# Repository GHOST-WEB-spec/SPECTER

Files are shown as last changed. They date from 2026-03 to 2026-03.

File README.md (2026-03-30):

# ⚡ SPECTER

A handheld ESP32-based cybersecurity research tool running JINX OS. Built from scratch — custom firmware, custom PCB, custom 3D printed enclosure.

## ✨ Features

**📡 WiFi**
- Network scanner with OUI vendor lookup and threat assessment
- Probe request sniffer
- Evil Twin access point with captive portal credential capture
- KARMA attack — automatically impersonates known networks

**🔴 IR**
- TV-B-Gone (26 codes, all major brands)
- IR blaster with capture and replay
- IR self-test

**📶 BLE**
- Scanner with Apple device detection
- Apple BLE proximity spam (6 payloads)

**🔜 Coming Soon**
- CC1101 sub-GHz scanner and replay
- NFC read/write/clone
- RFID read/clone
- BadUSB payloads
- Deauth and beacon flood

## 🔧 Hardware

- ESP32-WROVER on Freenove extension board
- 2.8" ILI9341 TFT touchscreen (240x320)
- VS1838B IR receiver + TSAL6400 IR LEDs
- CC1101 x2 (sub-GHz radios)
- PN532 NFC module
- RDM6300 RFID module
- LiPo 1000mAh + TP4056 charging
- Custom KiCad PCB — ordered from JLCPCB
- 3D printed enclosure — Fusion 360

## 🚀 Status

Firmware working. PCB designed and ready to order. Parts arriving shortly for final assembly.

## 🛠️ Build

Flash using Arduino IDE with ESP32 core v2.0.17. Partition scheme: Huge APP 3MB No OTA.

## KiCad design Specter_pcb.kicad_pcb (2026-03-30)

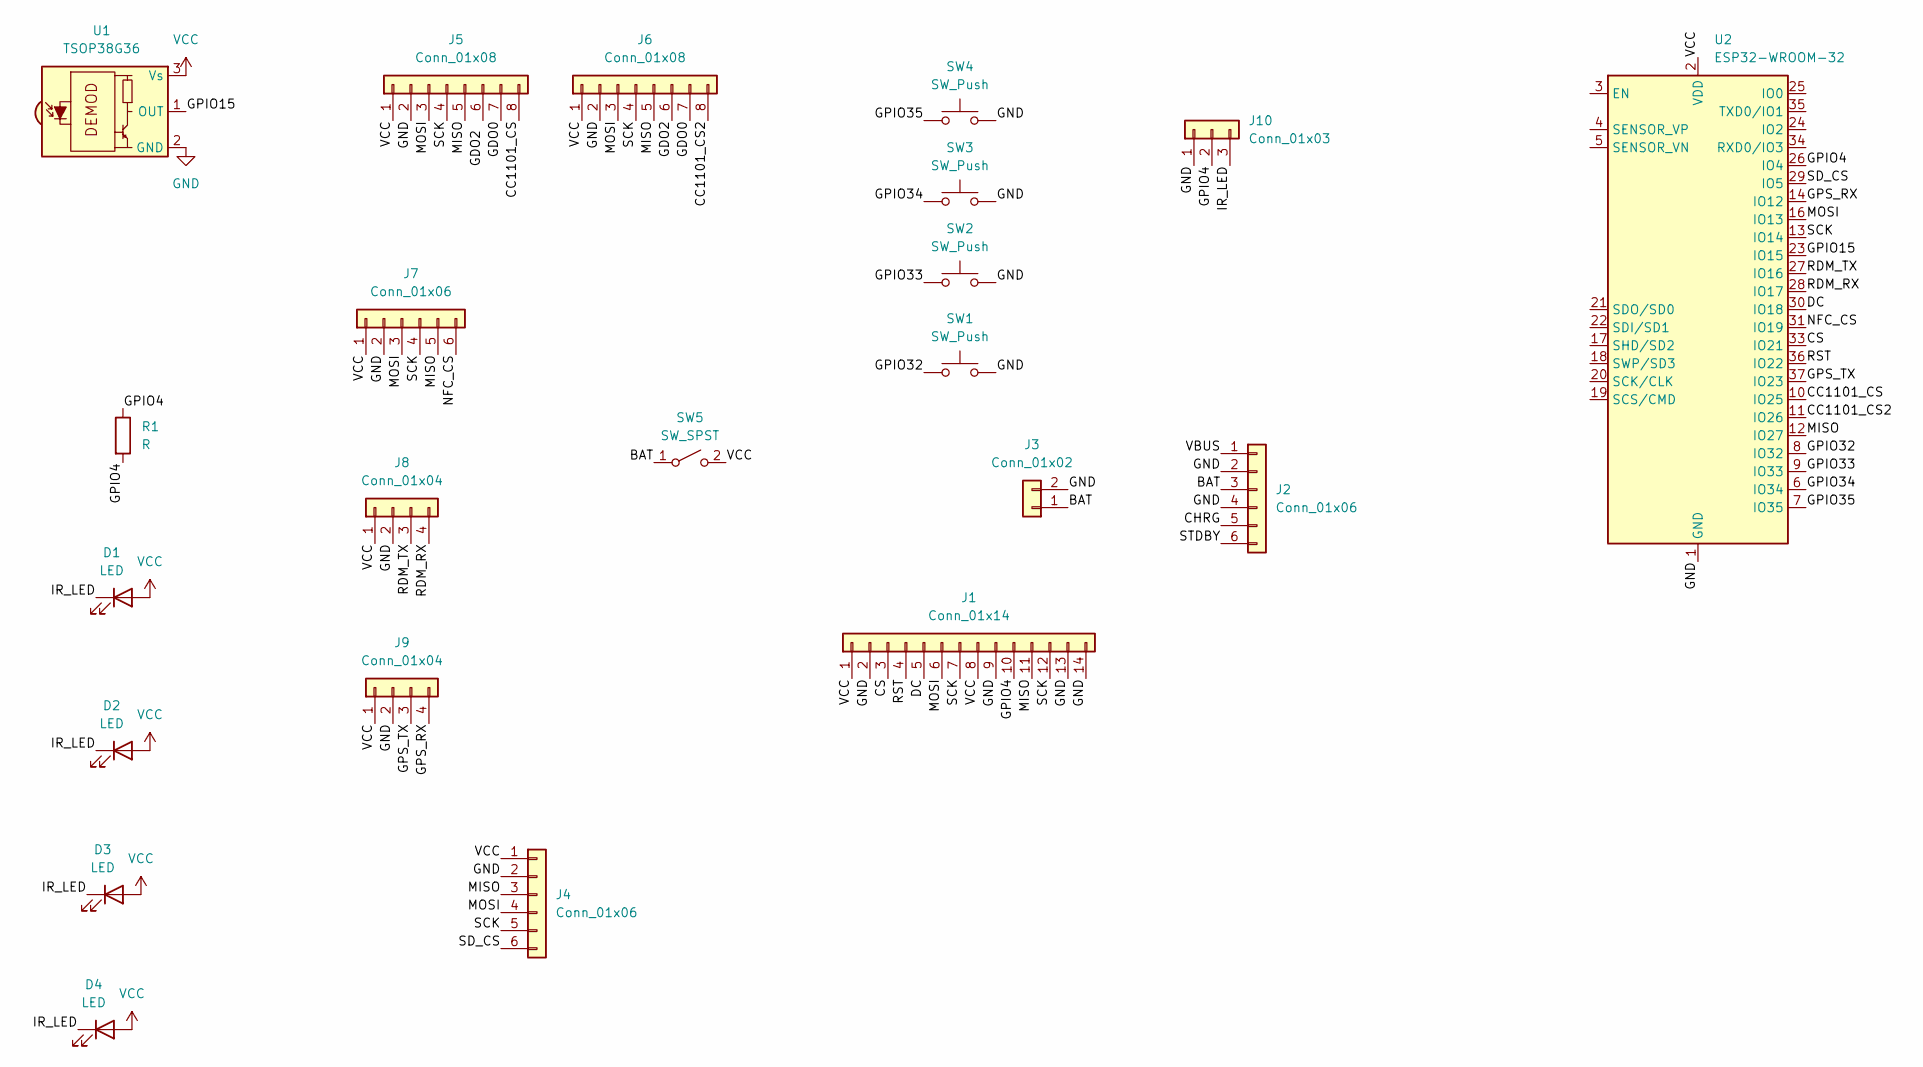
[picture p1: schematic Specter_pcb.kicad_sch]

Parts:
D1, D2, D3, D4: LED; LED_D5.0mm
J1: Conn_01x14; PinHeader_1x14_P2.54mm_Vertical
J2, J4, J7: Conn_01x06; PinHeader_1x06_P2.54mm_Vertical
J3: Conn_01x02; JST_PH_S2B-PH-K_1x02_P2.00mm_Horizontal
J5, J6: Conn_01x08; PinHeader_1x08_P2.54mm_Vertical
J8, J9: Conn_01x04; PinHeader_1x04_P2.54mm_Vertical
J10: Conn_01x03; PinHeader_1x03_P2.54mm_Vertical
R1: R; R_Axial_DIN0207_L6.3mm_D2.5mm_P7.62mm_Horizontal
SW1, SW2, SW3, SW4: SW_Push; SW_PUSH_6mm
SW5: SW_SPST; SW_NKK_BB15AH
U1: TSOP38G36; Vishay_MINICAST-3Pin
U2: ESP32-WROOM-32

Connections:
/BAT: J2.3, J3.1, SW5.1 (A)
/CC1101_CS: J5.8, U2.10 (IO25)
/CC1101_CS2: J6.8, U2.11 (IO26)
/CHRG: J2.5
/CS: J1.3, U2.33 (IO21)
/DC: J1.5, U2.30 (IO18)
/GDO0: J5.7, J6.7
/GDO2: J6.6
/GPIO4: J1.10, J10.2, R1.1, R1.2, U2.26 (IO4)
/GPIO15: U1.1 (OUT), U2.23 (IO15)
/GPIO32: SW1.1, U2.8 (IO32)
/GPIO33: SW2.1, U2.9 (IO33)
/GPIO34: SW3.1, U2.6 (IO34)
/GPIO35: SW4.1, U2.7 (IO35)
/GPS_RX: J9.4, U2.14 (IO12)
/GPS_TX: J9.3, U2.37 (IO23)
/IR_LED: D1.1 (K), D2.1 (K), D3.1 (K), D4.1 (K), J10.3
/MISO: J1.11, J4.3, J5.5, J6.5, J7.5, U2.12 (IO27)
/MOSI: J1.6, J4.4, J5.3, J6.3, J7.3, U2.16 (IO13)
/NFC_CS: J7.6, U2.31 (IO19)
/RDM_RX: J8.4, U2.28 (IO17)
/RDM_TX: J8.3, U2.27 (IO16)
/RST: J1.4, U2.36 (IO22)
/SCK: J1.7, J1.12, J4.5, J5.4, J6.4, J7.4, U2.13 (IO14)
/SD_CS: J4.6, U2.29 (IO5)
/STDBY: J2.6
/VBUS: J2.1
GND: J1.2, J1.9, J1.13, J1.14, J2.2, J2.4, J3.2, J4.2, J5.2, J6.2, J7.2, J8.2, J9.2, J10.1, SW1.2, SW2.2, SW3.2, SW4.2, U1.2 (GND), U2.1 (GND), U2.15 (GND), U2.38 (GND), U2.39 (GND)
VCC: D1.2 (A), D2.2 (A), D3.2 (A), D4.2 (A), J1.1, J1.8, J4.1, J5.1, J6.1, J7.1, J8.1, J9.1, SW5.2 (B), U1.3 (Vs), U2.2 (VDD)

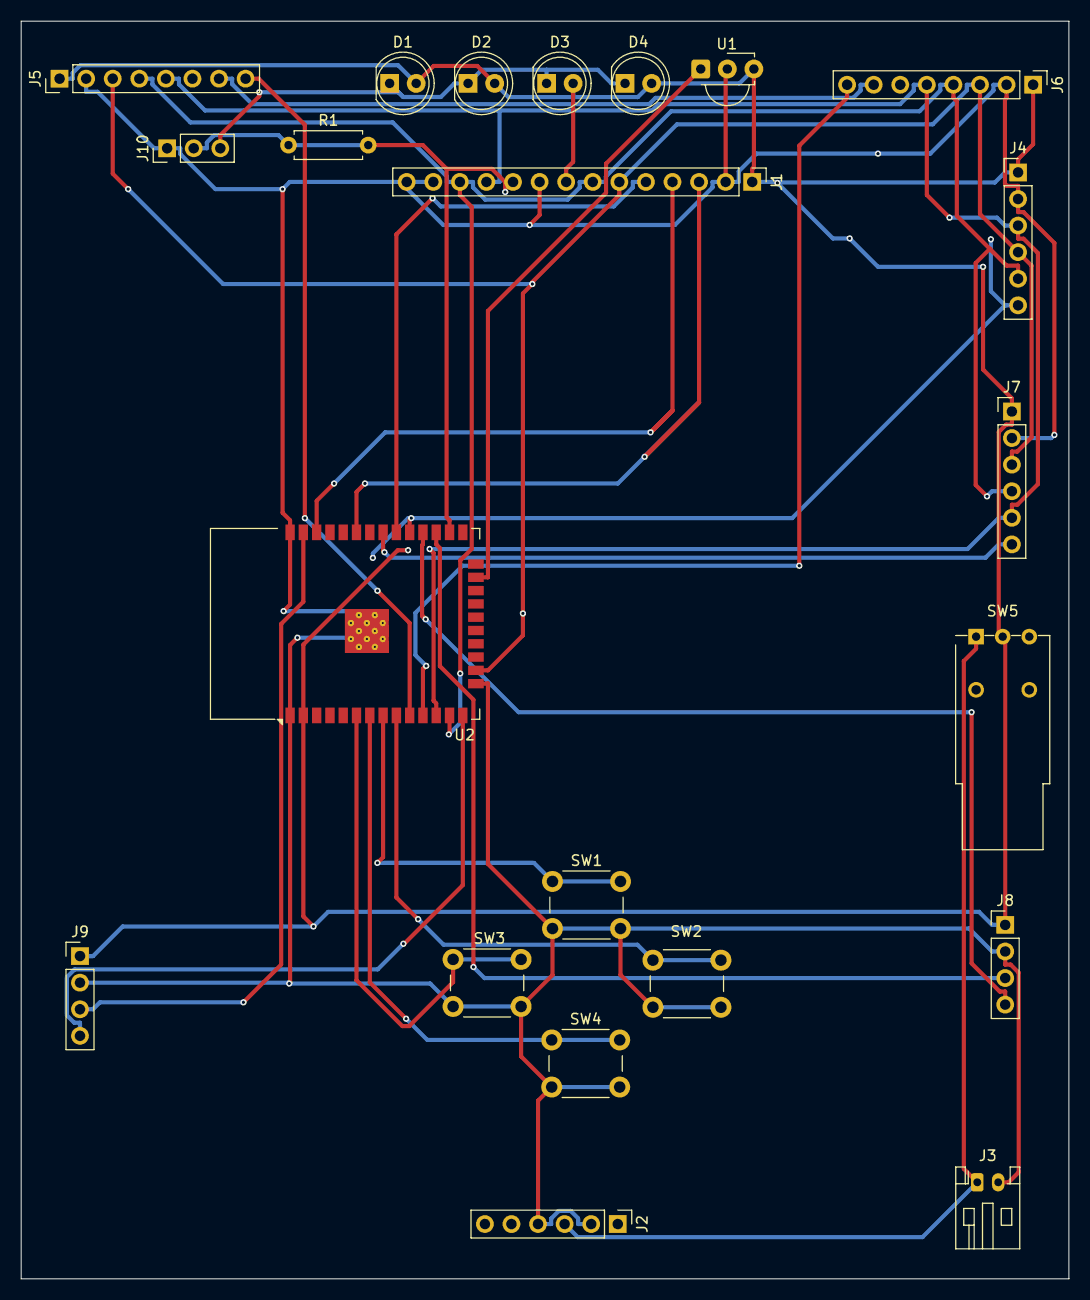
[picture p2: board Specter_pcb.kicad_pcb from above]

Board: 2 copper layers, 100.1 x 120.2 mm, 22 parts (0 on the bottom side), 25 nets.

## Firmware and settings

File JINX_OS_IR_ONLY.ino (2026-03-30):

// ============================================================
// JINX OS v9 — SPECTER
// Terminal Style UI — Green on Black
// ============================================================

#include <TFT_eSPI.h>
#include <SPI.h>
#include <IRremote.hpp>
#include <WiFi.h>
#include "esp_wifi.h"
#include <BLEDevice.h>
#include <BLEScan.h>
#include <BLEAdvertisedDevice.h>
#include <BLEAdvertising.h>
#include <WebServer.h>
#include <DNSServer.h>

// --- Pin definitions ---
#define IR_RECV_PIN  15
#define IR_BLAST_PIN 4

TFT_eSPI tft = TFT_eSPI();

// ============================================================
// COLOUR PALETTE
// ============================================================
#define C_BG       0x0000
#define C_GREEN    0x07E0
#define C_DGREEN   0x03E0
#define C_DDGREEN  0x01C0
#define C_WHITE    0xFFFF
#define C_GREY     0x8410
#define C_DGREY    0x2104
#define C_RED      0xF800
#define C_YELLOW   0xFFE0
#define C_CYAN     0x07FF
#define C_ORANGE   0xFD20
#define C_PURPLE   0x780F
#define C_BLUE     0x001F

// ============================================================
// STATES
// ============================================================
enum State {
  S_SPLASH, S_HOME,
  S_IR_MENU, S_IR_BLASTER, S_IR_TVBGONE, S_IR_SELFTEST,
  S_WIFI_MENU, S_WIFI_SCANNER, S_WIFI_DETAIL, S_WIFI_ATTACKS,
  S_WIFI_BEACON, S_WIFI_PROBE,
  S_BLE_MENU, S_BLE_SCANNER, S_BLE_SPAM,
  S_EVIL_TWIN, S_KARMA
};
State currentState = S_SPLASH;

// --- WiFi ---
int wifiCount     = 0;
int wifiScroll    = 0;
int wifiDetailIdx = -1;
bool wifiSortSig  = true;
int wifiIdx[64];

// --- Probe sniffer ---
bool probeRunning = false;
struct ProbeEntry { char mac[18]; char ssid[33]; int rssi; };
#define MAX_PROBES 20
ProbeEntry probeLog[MAX_PROBES];
int probeCount  = 0;
int probeScroll = 0;

// --- Evil Twin ---
bool evilTwinRunning = false;
int  evilTwinTargetIdx = -1;
struct CredEntry { char email[64]; char pass[64]; };
#define MAX_CREDS 20
CredEntry credLog[MAX_CREDS];
int credCount  = 0;
int credScroll = 0;
WebServer* evilServer = nullptr;
DNSServer* evilDNS    = nullptr;

// --- KARMA ---
#define KARMA_TARGET_SSID "TBFT"
bool karmaRunning = false;
struct KarmaEntry { char ssid[33]; char mac[18]; int count; };
#define MAX_KARMA 20
KarmaEntry karmaLog[MAX_KARMA];
int karmaCount  = 0;
int karmaScroll = 0;
WebServer* karmaServer = nullptr;
DNSServer* karmaDNS    = nullptr;

// --- BLE scanner ---
struct BLEEntry {
  char name[32];
  char mac[18];
  int  rssi;
  bool isApple;
};
#define MAX_BLE 30
BLEEntry bleLog[MAX_BLE];
int bleCount   = 0;
int bleScroll  = 0;
bool bleScanning = false;
BLEScan* pBLEScan = nullptr;

// --- BLE spam ---
bool bleSpamRunning = false;
int  bleSpamIdx     = 0;
int  bleSpamSent    = 0;

// --- IR ---
bool irListening = false;
bool irHasCode   = false;
uint32_t irValue = 0;
uint16_t irBits  = 0;
uint8_t  irProto = 0;

// --- Touch ---
uint16_t tx, ty;
unsigned long lastTouch = 0;
#define DEBOUNCE_MS 280

struct TVCode { uint8_t proto; uint32_t value; uint8_t bits; const char* brand; };

// ============================================================
// TOUCH
// ============================================================
bool getTouch(uint16_t &x, uint16_t &y) {
  uint16_t rx, ry;
  if (!tft.getTouch(&rx, &ry)) return false;
  x = map(ry, 299, 12, 0, 239);
  y = map(rx, 226, 11, 0, 319);
  x = constrain(x, 0, 239);
  y = constrain(y, 0, 319);
  return true;
}

// ============================================================
// PRIMITIVES
// ============================================================
void drawBar(const char* left, const char* right) {
  tft.fillRect(0, 0, 240, 14, C_DGREEN);
  tft.setTextColor(C_BG, C_DGREEN); tft.setTextSize(1);
  tft.setCursor(3, 3); tft.print(left);
  int rlen = strlen(right) * 6;
  tft.setCursor(237 - rlen, 3); tft.print(right);
}
void drawHeader(int y, const char* text) {
  tft.setTextColor(C_GREEN, C_BG); tft.setTextSize(1);
  tft.setCursor(0, y); tft.print("-- "); tft.print(text); tft.print(" ");
  int used = 3 + strlen(text) + 1;
  for (int i = used * 6; i < 240; i += 6) tft.print("-");
}
void drawBack() {
  tft.setTextColor(C_DGREEN, C_BG); tft.setTextSize(1);
  tft.setCursor(0, 17); tft.print("[<] BACK");
}
void drawBtn(int y, int h, const char* label, uint16_t col, bool active = true) {
  uint16_t bg = active ? C_DGREY : C_BG;
  tft.fillRect(0, y, 240, h, bg);
  tft.drawRect(0, y, 240, h, active ? col : C_DGREY);
  tft.fillRect(0, y, 3, h, col);
  tft.setTextColor(active ? col : C_DGREY, bg); tft.setTextSize(2);
  int tx2 = (240 - strlen(label) * 12) / 2;
  tft.setCursor(tx2, y + h/2 - 8); tft.print(label);
}
void drawTag(int x, int y, const char* text, uint16_t col) {
  int w = strlen(text) * 6 + 4;
  tft.drawRect(x, y, w, 10, col);
  tft.setTextColor(col, C_BG); tft.setTextSize(1);
  tft.setCursor(x + 2, y + 2); tft.print(text);
}
void drawHR(int y, uint16_t col = C_DGREEN) { tft.drawFastHLine(0, y, 240, col); }
bool backTapped(uint16_t x, uint16_t y) { return (y >= 0 && y <= 14); }

// ============================================================
// SPLASH
// ============================================================
void drawOniMask(int cx, int cy, int r) {
  tft.fillCircle(cx, cy, r, C_BG);
  tft.drawCircle(cx, cy, r, C_GREEN); tft.drawCircle(cx, cy, r-1, C_DGREEN);
  tft.fillCircle(cx-r/3, cy-r/6, r/5, C_GREEN); tft.fillCircle(cx+r/3, cy-r/6, r/5, C_GREEN);
  tft.fillCircle(cx-r/3, cy-r/6, r/10, C_BG);   tft.fillCircle(cx+r/3, cy-r/6, r/10, C_BG);
  tft.fillCircle(cx-r/3, cy-r/6, r/16, C_GREEN); tft.fillCircle(cx+r/3, cy-r/6, r/16, C_GREEN);
  tft.drawLine(cx-r/2, cy-r/2, cx-r/6, cy-r/3, C_GREEN);
  tft.drawLine(cx+r/2, cy-r/2, cx+r/6, cy-r/3, C_GREEN);
  tft.fillTriangle(cx, cy, cx-r/8, cy+r/4, cx+r/8, cy+r/4, C_DGREEN);
  tft.drawLine(cx-r/3, cy+r/2, cx+r/3, cy+r/2, C_GREEN);
  tft.drawLine(cx-r/3, cy+r/2, cx-r/2, cy+r/3, C_GREEN);
  tft.drawLine(cx+r/3, cy+r/2, cx+r/2, cy+r/3, C_GREEN);
  tft.fillRect(cx-r/4, cy+r/2-2, r/6, r/8, C_GREEN);
  tft.fillRect(cx+r/8, cy+r/2-2, r/6, r/8, C_GREEN);
  tft.fillTriangle(cx-r/2, cy-r, cx-r/3, cy-r-r/3, cx-r/6, cy-r, C_GREEN);
  tft.fillTriangle(cx+r/2, cy-r, cx+r/3, cy-r-r/3, cx+r/6, cy-r, C_GREEN);
}
void showSplash() {
  tft.fillScreen(C_BG);
  drawOniMask(120, 110, 55);
  tft.setTextColor(C_GREEN, C_BG); tft.setTextSize(3);
  tft.setCursor(28, 180); tft.print("SPECTER");
  tft.setTextColor(C_DGREEN, C_BG); tft.setTextSize(1);
  tft.setCursor(66, 207); tft.print("JINX OS v2.0");
  drawHR(220, C_DDGREEN); drawHR(222, C_DDGREEN);
  const char* bootLines[] = {
    "init hardware...", "mounting flash...",
    "loading IR db...", "wifi ready...", "boot ok."
  };
  int by = 228;
  for (int i = 0; i < 5; i++) {
    tft.setTextColor(C_DDGREEN, C_BG); tft.setTextSize(1);
    tft.setCursor(0, by); tft.print("> ");
    tft.setTextColor(C_DGREEN, C_BG); tft.print(bootLines[i]);
    by += 10; delay(120);
  }
  delay(400);
}

// ============================================================
// HOME
// ============================================================
void drawHomeScreen() {
  tft.fillScreen(C_BG);
  drawBar("SPECTER//JINX OS v2.0", "HOME");
  drawHR(14, C_DDGREEN);
  drawHeader(18, "SELECT MODULE");

  // IR
  tft.fillRect(0, 34, 240, 40, C_BG);
  tft.drawRect(0, 34, 240, 40, C_DGREEN);
  tft.fillRect(0, 34, 3, 40, C_RED);
  tft.setTextColor(C_RED, C_BG); tft.setTextSize(1); tft.setCursor(10, 38); tft.print("[IR]");
  tft.setTextColor(C_GREEN, C_BG); tft.setTextSize(2); tft.setCursor(10, 50); tft.print("INFRARED");
  drawHR(75, C_DDGREEN);

  // WiFi
  tft.fillRect(0, 77, 240, 40, C_BG);
  tft.drawRect(0, 77, 240, 40, C_DGREEN);
  tft.fillRect(0, 77, 3, 40, C_CYAN);
  tft.setTextColor(C_CYAN, C_BG); tft.setTextSize(1); tft.setCursor(10, 81); tft.print("[WiFi]");
  tft.setTextColor(C_GREEN, C_BG); tft.setTextSize(2); tft.setCursor(10, 93); tft.print("WIRELESS");
  drawHR(118, C_DDGREEN);

  // BLE
  tft.fillRect(0, 120, 240, 40, C_BG);
  tft.drawRect(0, 120, 240, 40, C_DGREEN);
  tft.fillRect(0, 120, 3, 40, C_BLUE);
  tft.setTextColor(C_BLUE, C_BG); tft.setTextSize(1); tft.setCursor(10, 124); tft.print("[BLE]");
  tft.setTextColor(C_GREEN, C_BG); tft.setTextSize(2); tft.setCursor(10, 136); tft.print("BLUETOOTH");
  drawHR(161, C_DDGREEN);

  tft.setTextColor(C_DDGREEN, C_BG); tft.setTextSize(1);
  tft.setCursor(0, 168); tft.print("> [SUB-GHZ]  coming soon");
  tft.setCursor(0, 181); tft.print("> [NFC]      coming soon");
  tft.setCursor(0, 194); tft.print("> [BADUSB]   coming soon");
  drawHR(207, C_DDGREEN);
  tft.setTextColor(C_DDGREEN, C_BG);
  tft.setCursor(0, 211); tft.print("specter//ready_");
}

bool homeIRTapped(uint16_t x, uint16_t y)   { return (y >= 34  && y <= 75); }
bool homeWiFiTapped(uint16_t x, uint16_t y) { return (y >= 77  && y <= 118); }
bool homeBLETapped(uint16_t x, uint16_t y)  { return (y >= 120 && y <= 161); }

// ============================================================
// IR MENU
// ============================================================
void drawIRMenu() {
  tft.fillScreen(C_BG);
  drawBar("SPECTER//IR", "INFRARED");
  drawBack();
  drawHeader(30, "IR MODULE");
  drawBtn(42, 55, "IR BLASTER", C_RED, true);
  tft.setTextColor(C_DGREEN, C_DGREY); tft.setTextSize(1);
  tft.setCursor(6, 75); tft.print("capture + replay IR codes");
  drawHR(98, C_DDGREEN);
  drawBtn(101, 55, "TV-B-GONE", C_DGREEN, true);
  tft.setTextColor(C_DGREEN, C_DGREY); tft.setTextSize(1);
  tft.setCursor(6, 134); tft.print("blast all TV power codes");
  drawTag(178, 103, "READY", C_DGREEN);
  drawHR(157, C_DDGREEN);
  drawBtn(160, 55, "SELF TEST", C_YELLOW, true);
  tft.setTextColor(C_DGREEN, C_DGREY); tft.setTextSize(1);
  tft.setCursor(6, 193); tft.print("loop test: blast+recv verify");
  drawTag(165, 162, "DIAG", C_YELLOW);
}
bool irMenuBlasterTapped(uint16_t x, uint16_t y)  { return (y >= 42  && y <= 97); }
bool irMenuTVBGoneTapped(uint16_t x, uint16_t y)  { return (y >= 101 && y <= 156); }
bool irMenuSelfTestTapped(uint16_t x, uint16_t y) { return (y >= 160 && y <= 215); }

// ============================================================
// IR BLASTER
// ============================================================
void drawIRBlaster() {
  tft.fillScreen(C_BG);
  drawBar("SPECTER//IR", "BLASTER");
  drawBack();
  drawHeader(30, "IR BLASTER");
  tft.drawRect(0, 42, 240, 72, C_DGREEN);
  tft.fillRect(0, 42, 3, 72, irHasCode ? C_GREEN : C_DGREY);
  if (!irHasCode) {
    tft.setTextColor(C_DGREEN, C_BG); tft.setTextSize(1);
    tft.setCursor(6, 50); tft.print("> no signal captured");
    tft.setCursor(6, 63); tft.print("> press LISTEN");
    tft.setCursor(6, 76); tft.print("> point remote at GPIO15");
    tft.setTextColor(C_DDGREEN, C_BG); tft.setCursor(6, 95); tft.print("status: waiting_");
  } else {
    tft.setTextColor(C_GREEN, C_BG); tft.setTextSize(1);
    tft.setCursor(6, 50); tft.print("> signal locked");
    tft.setTextColor(C_DGREEN, C_BG); tft.setCursor(6, 63); tft.print("proto: ");
    tft.setTextColor(C_GREEN, C_BG); tft.print(getProtocolString((decode_type_t)irProto));
    tft.setTextColor(C_DGREEN, C_BG); tft.setCursor(6, 76); tft.print("value: ");
    tft.setTextColor(C_YELLOW, C_BG); tft.print("0x"); tft.print(irValue, HEX);
    tft.setTextColor(C_DGREEN, C_BG); tft.setCursor(6, 89); tft.print("bits:  ");
    tft.setTextColor(C_GREEN, C_BG); tft.print(irBits);
    tft.setCursor(170, 95); tft.print("[LOCKED]");
  }
  drawHR(115, C_DDGREEN);
  uint16_t lCol = irListening ? C_GREEN : C_DGREEN;
  drawBtn(118, 50, irListening ? "// LISTENING" : "LISTEN", lCol, true);
  if (irListening) {
    tft.setTextColor(C_GREEN, C_DGREY); tft.setTextSize(1);
    tft.setCursor(6, 154); tft.print("receiving on GPIO15...");
  }
  drawHR(169, C_DDGREEN);
  drawBtn(172, 50, "BLAST", irHasCode ? C_RED : C_DGREY, irHasCode);
  if (!irHasCode) {
    tft.setTextColor(C_DGREY, C_BG); tft.setTextSize(1);
    tft.setCursor(6, 208); tft.print("capture a signal first");
  }
}
bool irBlasterListenTapped(uint16_t x, uint16_t y) { return (y >= 118 && y <= 168); }
bool irBlasterBlastTapped(uint16_t x, uint16_t y)  { return (y >= 172 && y <= 222); }

void doBlast() {
  if (!irHasCode) return;
  tft.fillScreen(C_BG); drawBar("SPECTER//IR", "TRANSMIT");
  tft.setTextColor(C_RED, C_BG); tft.setTextSize(2);
  tft.setCursor(40, 120); tft.print("BLASTING...");
  tft.setTextColor(C_DGREEN, C_BG); tft.setTextSize(1);
  tft.setCursor(0, 150); tft.print("> transmitting IR signal");
  tft.setCursor(0, 163); tft.print("> repeat x15");
  delay(200);
  IRData irData;
  irData.protocol = (decode_type_t)irProto;
  irData.address  = (irValue >> 16) & 0xFFFF;
  irData.command  = irValue & 0xFFFF;
  irData.numberOfBits = irBits; irData.flags = 0;
  IrSender.begin(IR_BLAST_PIN);
  if (irProto == SONY) {
    uint8_t cmd = irData.command & 0x7F; uint8_t addr = irData.address & 0x1F;
    uint16_t sirc = (addr << 7) | cmd;
    for (int i = 0; i < 15; i++) { IrSender.sendSony(sirc, 12); delay(45); }
  } else {
    for (int i = 0; i < 20; i++) { IrSender.write(&irData, 0); delay(100); }
  }
  tft.setTextColor(C_GREEN, C_BG); tft.setCursor(0, 180); tft.print("> done.");
  delay(500); drawIRBlaster();
}

// ============================================================
// IR SELF TEST
// ============================================================
void drawIRSelfTest(int phase, bool passed) {
  tft.fillScreen(C_BG); drawBar("SPECTER//IR", "SELF TEST");
  drawBack(); drawHeader(30, "LOOP DIAGNOSTIC");
  tft.setTextColor(C_DGREEN, C_BG); tft.setTextSize(1);
  tft.setCursor(0, 42); tft.print("> cup hand over IR LEDs+recv");
  tft.setCursor(0, 55); tft.print("> test fires code + listens");
  tft.setCursor(0, 68); tft.print("> pass = IR circuit confirmed");
  drawHR(80, C_DDGREEN);
  uint16_t col1 = phase >= 1 ? C_GREEN : C_DGREY;
  uint16_t col2 = phase >= 2 ? C_GREEN : C_DGREY;
  uint16_t col3 = phase >= 3 ? (passed ? C_GREEN : C_RED) : C_DGREY;
  tft.setTextColor(col1, C_BG); tft.setCursor(0, 90);
  tft.print(phase >= 1 ? "> [OK] blasting Sony code..." : "> [ ] blast IR code");
  tft.setTextColor(col2, C_BG); tft.setCursor(0, 103);
  tft.print(phase >= 2 ? "> [OK] listening on GPIO15..." : "> [ ] switch to receive");
  tft.setTextColor(col3, C_BG); tft.setCursor(0, 116);
  if      (phase < 3)  tft.print("> [ ] check signal received");
  else if (passed)     tft.print("> [PASS] signal received!");
  else                 tft.print("> [FAIL] no signal detected");
  drawHR(130, C_DDGREEN);
  if (phase == 0) {
    drawBtn(133, 50, "RUN TEST", C_YELLOW, true);
    tft.setTextColor(C_DGREEN, C_BG); tft.setTextSize(1);
    tft.setCursor(0, 195); tft.print("> cup hand over device first");
  } else if (phase == 3) {
    if (passed) {
      tft.setTextColor(C_GREEN, C_BG); tft.setTextSize(2);
      tft.setCursor(50, 148); tft.print("IR OK!");
      tft.setTextColor(C_DGREEN, C_BG); tft.setTextSize(1);
      tft.setCursor(0, 178); tft.print("> hardware confirmed working");
      tft.setCursor(0, 191); tft.print("> range issue = LED power");
    } else {
      tft.setTextColor(C_RED, C_BG); tft.setTextSize(2);
      tft.setCursor(30, 148); tft.print("IR FAIL");
      tft.setTextColor(C_DGREEN, C_BG); tft.setTextSize(1);
      tft.setCursor(0, 178); tft.print("> check wiring GPIO4 + 15");
      tft.setCursor(0, 191); tft.print("> check LED orientation");
    }
    drawBtn(210, 40, "RETRY", C_YELLOW, true);
  }
}
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
void loop() {
  if (currentState == S_IR_BLASTER && irListening) {
    if (IrReceiver.decode()) {
      irValue = IrReceiver.decodedIRData.decodedRawData;
      irBits  = IrReceiver.decodedIRData.numberOfBits;
      irProto = (uint8_t)IrReceiver.decodedIRData.protocol;
      IrReceiver.resume();
      if (irValue != 0) {
        irHasCode = true; irListening = false;
        IrReceiver.stop(); drawIRBlaster();
      } else IrReceiver.resume();
    }
  }

  static unsigned long lastProbeRefresh = 0;
  if (currentState == S_WIFI_PROBE && probeRunning) {
    unsigned long now2 = millis();
    if (now2 - lastProbeRefresh > 1000) { lastProbeRefresh = now2; drawProbeScreen(true); }
  }

  unsigned long now = millis();
  if (now - lastTouch < DEBOUNCE_MS) return;
  if (!getTouch(tx, ty)) return;
  lastTouch = now;
  Serial.print("t:"); Serial.print(tx); Serial.print(","); Serial.println(ty);

  switch (currentState) {
    case S_HOME:
      if      (homeIRTapped(tx,ty))   { currentState=S_IR_MENU;   drawIRMenu(); }
      else if (homeWiFiTapped(tx,ty)) { currentState=S_WIFI_MENU; drawWiFiMenu(); }
      else if (homeBLETapped(tx,ty))  { currentState=S_BLE_MENU;  drawBLEMenu(); }
      break;

    case S_IR_MENU:
      if      (backTapped(tx,ty))           { currentState=S_HOME;        drawHomeScreen(); }
      else if (irMenuBlasterTapped(tx,ty))  { currentState=S_IR_BLASTER;  irListening=false; drawIRBlaster(); }
      else if (irMenuTVBGoneTapped(tx,ty))  { currentState=S_IR_TVBGONE;  drawTVBGone(); }
      else if (irMenuSelfTestTapped(tx,ty)) { currentState=S_IR_SELFTEST; drawIRSelfTest(0, false); }
      break;

    case S_IR_BLASTER:
      if (backTapped(tx,ty)) {
        if (irListening) { irListening=false; IrReceiver.stop(); }
        currentState=S_IR_MENU; drawIRMenu();
      } else if (irBlasterListenTapped(tx,ty)) {
        irListening=!irListening;
        if (irListening) IrReceiver.begin(IR_RECV_PIN, DISABLE_LED_FEEDBACK);
        else IrReceiver.stop();
        drawIRBlaster();
      } else if (irBlasterBlastTapped(tx,ty)) doBlast();
      break;

    case S_IR_TVBGONE:
      if      (backTapped(tx,ty) && !tvbRunning) { currentState=S_IR_MENU; drawIRMenu(); }
      else if (tvbFireTapped(tx,ty) && !tvbRunning) runTVBGone();
      break;

    case S_IR_SELFTEST:
      if      (backTapped(tx,ty))            { currentState=S_IR_MENU; drawIRMenu(); }
      else if (irSelfTestRunTapped(tx,ty))   { runIRSelfTest(); }
      else if (irSelfTestRetryTapped(tx,ty)) { drawIRSelfTest(0, false); }
      break;

    case S_WIFI_MENU:
      if      (backTapped(tx,ty))            { currentState=S_HOME;         drawHomeScreen(); }
      else if (wifiMenuScannerTapped(tx,ty)) { currentState=S_WIFI_SCANNER; drawWiFiScanner(); }
      else if (wifiMenuAttacksTapped(tx,ty)) { currentState=S_WIFI_ATTACKS; drawWiFiAttacks(); }
      break;

    case S_WIFI_ATTACKS:
      if      (backTapped(tx,ty))                  { currentState=S_WIFI_MENU;  drawWiFiMenu(); }
      else if (wifiAttacksProbeTapped(tx,ty))       { currentState=S_WIFI_PROBE; drawProbeScreen(false); }
      else if (wifiAttacksEvilTwinTapped(tx,ty))   { evilTwinTargetIdx=-1; currentState=S_EVIL_TWIN; drawEvilTwinScreen(false); }
      else if (wifiAttacksKarmaTapped(tx,ty))      { currentState=S_KARMA; drawKarmaScreen(false); }
      break;

    case S_KARMA:
      if (backTapped(tx,ty) && !karmaRunning)      { currentState=S_WIFI_ATTACKS; drawWiFiAttacks(); }
      else if (karmaBtnTapped(tx,ty) && !karmaRunning) { runKarma(); }
      break;

    case S_EVIL_TWIN:
      if (backTapped(tx,ty) && !evilTwinRunning)   { currentState=S_WIFI_ATTACKS; drawWiFiAttacks(); }
      else if (evilTwinBtnTapped(tx,ty) && !evilTwinRunning) { runEvilTwin(); }
      break;

    case S_WIFI_SCANNER:
      if (backTapped(tx,ty)) {
        WiFi.scanDelete(); wifiCount=0;
        currentState=S_WIFI_MENU; drawWiFiMenu();
      } else if (wifiScannerScanTapped(tx,ty)) {
        doWiFiScan();
      } else if (wifiCount > 0) {
        int tapped = wifiRowTapped(tx,ty);
        if (tapped >= 0) { wifiDetailIdx=tapped; currentState=S_WIFI_DETAIL; drawWiFiDetail(tapped); }
        else if (wifiScannerScrollUp(tx,ty) && wifiScroll > 0) { wifiScroll--; drawWiFiScanner(); }
        else if (wifiScannerScrollDown(tx,ty) && wifiScroll+SCAN_MAX_ROWS < wifiCount) { wifiScroll++; drawWiFiScanner(); }
      }
      break;

    case S_WIFI_DETAIL:
      if (backTapped(tx,ty)) { currentState=S_WIFI_SCANNER; drawWiFiScanner(); }
      else if (wifiDetailEvilTwinTapped(tx,ty)) {
        evilTwinTargetIdx = wifiDetailIdx;
        currentState = S_EVIL_TWIN;
        drawEvilTwinScreen(false);
      }
      break;

    case S_WIFI_PROBE:
      if (backTapped(tx,ty)) {
        if (probeRunning) stopProbeSniffer();
        currentState=S_WIFI_ATTACKS; drawWiFiAttacks();
      } else if (probeBtnTapped(tx,ty)) {
        if (!probeRunning) { startProbeSniffer(); drawProbeScreen(true); }
        else { stopProbeSniffer(); drawProbeScreen(false); }
      } else if (probeScrollUp(tx,ty) && probeScroll > 0) { probeScroll--; drawProbeScreen(probeRunning); }
      else if (probeScrollDown(tx,ty) && probeScroll+9 < probeCount) { probeScroll++; drawProbeScreen(probeRunning); }
      break;

    case S_BLE_MENU:
      if      (backTapped(tx,ty))        { currentState=S_HOME;        drawHomeScreen(); }
      else if (bleScannerTapped(tx,ty))  { currentState=S_BLE_SCANNER; drawBLEScanner(false); }
      else if (bleSpamTapped(tx,ty))     { currentState=S_BLE_SPAM;    drawAppleSpamScreen(false, 0, 0); }
      break;

    case S_BLE_SCANNER:
      if (backTapped(tx,ty)) { currentState=S_BLE_MENU; drawBLEMenu(); }
      else if (bleScanBtnTapped(tx,ty) && !bleScanning) { doBLEScan(); }
      else if (bleScanScrollUp(tx,ty) && bleScroll > 0) { bleScroll--; drawBLEScanner(false); }
      else if (bleScanScrollDown(tx,ty) && bleScroll+10 < bleCount) { bleScroll++; drawBLEScanner(false); }
      break;

    case S_BLE_SPAM:
      if (backTapped(tx,ty) && !bleSpamRunning) { currentState=S_BLE_MENU; drawBLEMenu(); }
      else if (appleSpamBtnTapped(tx,ty) && !bleSpamRunning) { runAppleSpam(); }
      break;

    default: break;
  }
}
